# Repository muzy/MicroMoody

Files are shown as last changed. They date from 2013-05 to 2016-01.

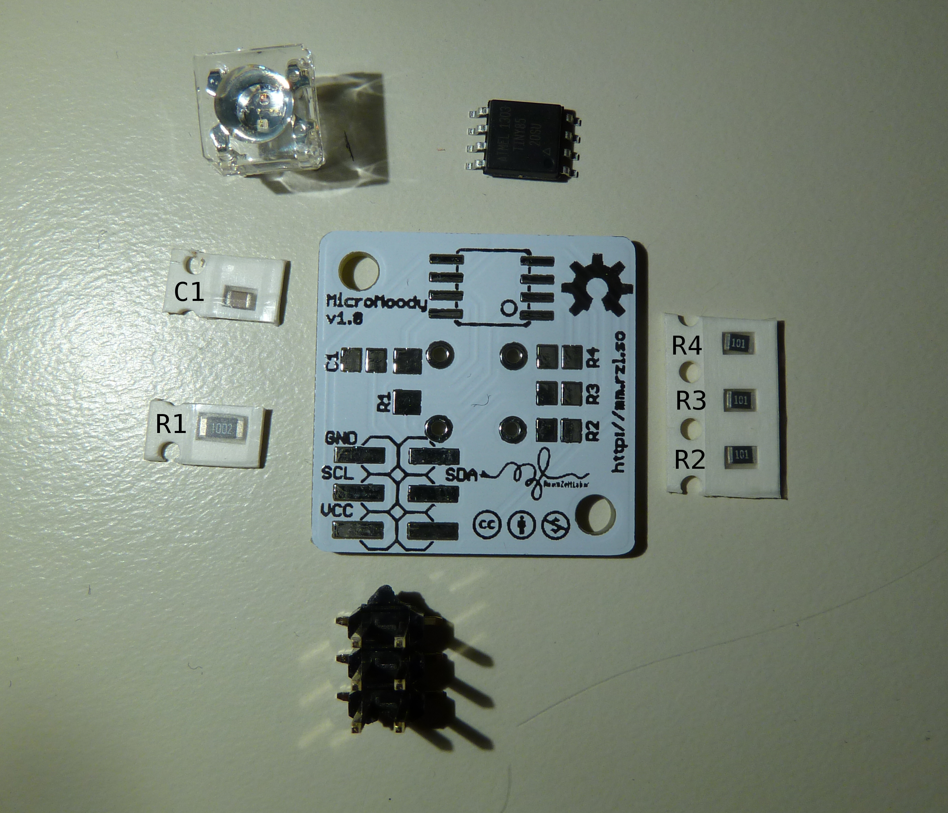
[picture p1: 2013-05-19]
doc/parts.jpg

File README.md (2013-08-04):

# MicroMoody

RGB LED driven by an ATTiny85. Largely blink(1)-compatible, except that it uses
I2C instead of USB.

## setup

See <https://wiki.chaosdorf.de/MicroMoody> and
<https://wiki.raumzeitlabor.de/wiki/MicroMoody> for soldering instructions.

For the firmware, run `make && make program`. You may need to edit the
Makefile to fit your programmer, it's written for an usbasp.

## remote control (I2C)

This is enabled by the `-DI2CEN` compile flag, which is set by default in the
Makefile. Hardware pull-ups on SCL and SDA are required (1.5 kOhm recommended)

After sending the 7bit address and the r/!w bit,
the bus master must send the following 7 bytes to the MicroMoody:

* command
* delay
* red value
* green value
* blue value
* payload address (high byte)
* payload address (low byte)

The default I2C address is `0x11` (17),
The default payload address is `0x0001`. The idea behind this distinction is
to use the I2C address to talk to any micromoody, and the payload address to
select the specific micromoody to address. This way, you can have various
other I2C devices and up to 65534 MicroMoodies on the same bus
(just in case you need to).

Commands with the broadcast payload address of `0xffff` are always accepted,
even when they contain the "set address" opmode.

red, green and blue are the color value, 0 is off, 0xff is full brightness.

There are several types of commands:

### command 0 .. 63 (set mode of operation)

The red, green and blue bytes are "don't care" unless a command is
marked `RGB`.

*   0: steady `RGB` light
*   1: rainbow colors, hard transitions
*   2: random colors, hard transitions
*   3: `RGB` color, blink on/off
*   4: steady light, fade to specified `RGB` color
*   5: rainbow colors, fading transitions
*   6: random colors, fading transitions
*   7: `RGB` color, fade on/off
*  63: Run animation. It will start in slot 1 and end in the slot last set
       (see also below)

modes 8 to 62 are reserved for further blink / fade modes.

### command 64 .. 127 (animation sequences)

*  64: Save `RGB` + delay in animation slot 1
* ...
* 127: Save `RGB` + delay in animation slot 64

For instance, to set a steady red pulse, you can transmit (in hex)
`40 10 ff 00 00 ff ff`, `41 10 50 00 00 ff ff`. This will make the animation
run in slot 1 -> slot 2 -> slot 1 -> ....

Note that this does not start the animation yet, use `3f XX XX XX XX ff ff`
for that. Also note that the upper bound of the current sequence is
determined by the last animation command. So if you send `40 ...`,
`41 ...`, `42 ...`, `40 ...`, the animation run will be
slot 1 -> slot 1 -> slot 1 -> .... (i.e. a steady color).

Refer to example/\*/rgbpulse for a more sophisticated example.

### command 128 .. 239

reserved

### command 240 .. 255 (EEPROM)

These commands access the EEPROM. Writing one byte takes about 3.4ms and is
implemented synchronously, so expect them to be slow. They may even cause I2C
bus timeouts (which do not indicate write failures).

* 240: Save current mode of operation (last command &lt; 64) to EEPROM to be
       recalled after a power cycle. NOTE: if the current opmode is 63
       (animation), this may take up to 1 second (~12ms for each used animation
       slot)
* 241: Set address to color bytes. payload high = red, payload low = green,
       i2c = blue. This will also set the operation mode to random fading.
       Note that for i2c, the least significant 7 bit are the address, while
       the most significant bit is ignored

commands 242 to 255 are reserved for further EEPROM commands.

## I2C master hardware

If you have an Arduino, see `examples/arduino/SerialToI2C` for a USB-Serial
to I2C interface.

Otherwise, see [vusb-i2c](https://github.com/derf/vusb-i2c) for a
general-purpose USB-I2C tool based on VUSB.

## recognizing the firmware state

At the time of this writing, a newly flashed MicroMoody with default address
will run the RGB blink mode (starting with yellow), while a newly flashed
MicroMoody with only the addresses changed and no mode set will run in
rgb fading mode (starting with green).

## I2C master operation

When compiled with -DI2CMASTER (disabled by default), the MicroMoody will act
as I2C bus master. After each transition (after half the time until the next
transition has passed) it will send its current color and fade delay as a
broadcast (payload address 0xffff) over the bus. The I2C address used will be
the MicroMoody's I2C address (see above for default).

If it is operating with hard transitions, so will the slaves. same for soft
(fading) transitions.

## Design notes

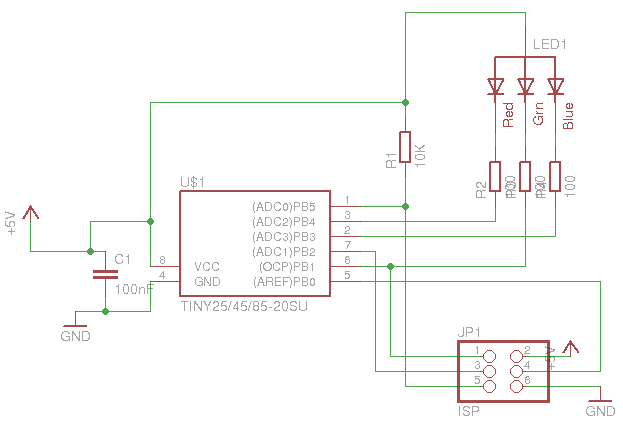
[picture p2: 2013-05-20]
schematics/circuit.png

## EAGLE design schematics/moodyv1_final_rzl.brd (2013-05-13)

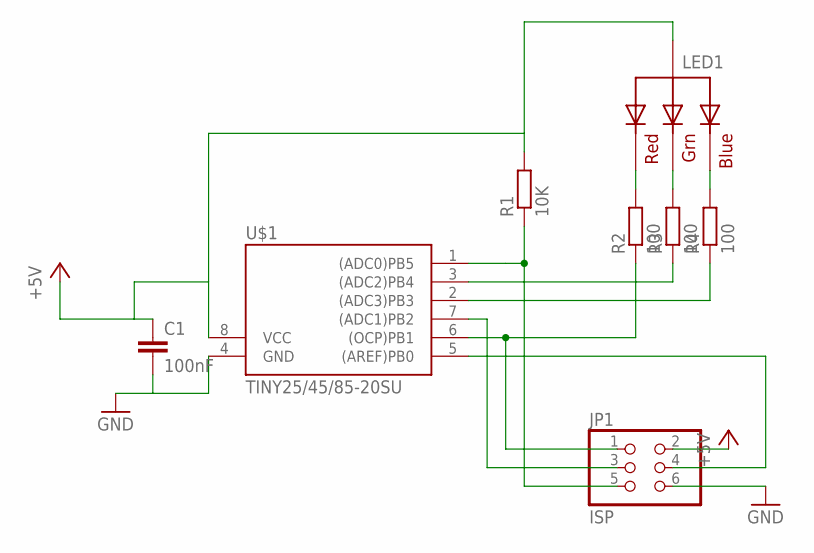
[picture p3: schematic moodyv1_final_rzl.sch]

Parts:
C1: 100nF; C0805
JP1: ISP; 2X03SMD
LED1: RGBLED_CA-PIRANHA; PIRANHA5MM
R1: 10K; R1206
R2, R3, R4: 100; R0805
U$1: TINY25/45/85-20SU; SOIC8

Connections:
+5V: C1.1, JP1.2, LED1.4 (VCC), R1.2, U$1.8 (VCC)
GND: C1.2, JP1.6, U$1.4 (GND)
unnamed: JP1.5, R1.1, U$1.1 ((ADC0)PB5)
unnamed: LED1.2 (RED), R2.2
unnamed: LED1.3 (GREEN), R3.2
unnamed: LED1.1 (BLUE), R4.2
unnamed: JP1.4, U$1.5 ((AREF)PB0)
unnamed: JP1.3, U$1.7 ((ADC1)PB2)
unnamed: JP1.1, R2.1, U$1.6 ((OCP)PB1)
unnamed: R4.1, U$1.2 ((ADC3)PB3)
unnamed: R3.1, U$1.3 ((ADC2)PB4)

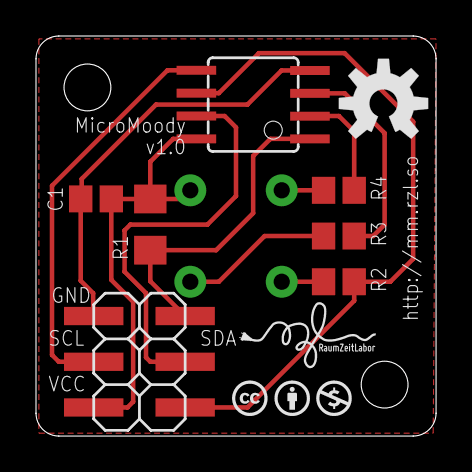
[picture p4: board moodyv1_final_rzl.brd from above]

Board: 2 copper layers, 22.2 x 22.2 mm, 8 parts (1 on the bottom side), 11 nets.

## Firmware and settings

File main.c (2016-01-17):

/*
 * Copyright (c) 2013, Daniel Friesel <derf@chaosdorf.de>
 *
 * Permission to use, copy, modify, and/or distribute this software for any
 * purpose with or without fee is hereby granted, provided that the above
 * copyright notice and this permission notice appear in all copies.
 */

#include <avr/eeprom.h>
#include <avr/io.h>
#include <stdlib.h>
#include <avr/pgmspace.h>
#include <avr/interrupt.h>

/*
 * PB1: green (OC1A)
 * PB3: blue  (soft pwm)
 * PB4: red   (OC1B)
 */

#define VRED   ( OCR1B   )
#define VGREEN ( OCR1A   )
#define VBLUE  ( is_blue )

#define OM_MODE_STEADY        (  0)
#define OM_MODE_BLINKRGB      (  1)
#define OM_MODE_BLINKRAND     (  2)
#define OM_MODE_BLINKONOFF    (  3)
#define OM_MODE_FADETOSTEADY  (  4)
#define OM_MODE_FADERGB       (  5)
#define OM_MODE_FADERAND      (  6)
#define OM_MODE_FADEONOFF     (  7)
#define OM_MODE_TEMPERATURE   (  8)
#define OM_MODE_STARTANIM     ( 63)
#define OM_MODE_ANIM_LOW      ( 64)
#define OM_MODE_ANIM_HIGH     (127)
#define OM_MODE_SAVESTATE     (240)
#define OM_MODE_SETADDR       (241)

#define TEMPERATURE_ZERO (355)

#define P_SDA PB0
#define P_SCL PB2

#ifdef I2CMASTER
#undef I2CEN
#endif

volatile uint8_t want_blue,  cache_blue;
volatile uint8_t want_green, cache_green;
volatile uint8_t want_red,   cache_red;

volatile uint8_t is_blue = 0;
volatile uint8_t opmode, speed;

volatile uint8_t seq[257];
volatile uint8_t step = 0;
volatile uint16_t animstep = 0;

volatile uint8_t addr_hi  = 0x00;
volatile uint8_t addr_lo  = 0x01;
volatile uint8_t addr_i2c = 0x11;

volatile enum {
	S_NONE, S_ACK, S_BYTE } comm_status = S_NONE;

uint8_t ee_valid, ee_mode, ee_speed, ee_red, ee_green, ee_blue EEMEM;
uint8_t ee_seq[257] EEMEM;
uint8_t ee_addrhi, ee_addrlo, ee_addri2c EEMEM;

const uint8_t pwmtable[32] PROGMEM = {
	0, 1, 2, 2, 2, 3, 3, 4, 5, 6, 7, 8, 10, 11, 13, 16, 19, 23,
	27, 32, 38, 45, 54, 64, 76, 91, 108, 128, 152, 181, 215, 255
};

int main (void)
{
	
	DDRB = _BV(DDB1) | _BV(DDB3) | _BV(DDB4);
	PORTB = _BV(PB1) | _BV(PB3) | _BV(PB4);

	uint8_t cnt = 0;

	WDTCR = _BV(WDE) | _BV(WDP3);

	TCCR0A = _BV(WGM01) | _BV(WGM00);
	TCCR0B = _BV(CS01);
	TIMSK = _BV(TOIE0);

	GTCCR = _BV(PWM1B) | _BV(COM1B1) | _BV(COM1B0);
	TCCR1 = _BV(PWM1A) | _BV(COM1A1) | _BV(COM1A0) | _BV(CS10);
	OCR1A = 0;
	OCR1B = 0;
	OCR1C = 0xff;

	if (eeprom_read_byte(&ee_valid) == 1) {
		VRED   = want_red   = cache_red   = eeprom_read_byte(&ee_red);
		VGREEN = want_green = cache_green = eeprom_read_byte(&ee_green);
		VBLUE  = want_blue  = cache_blue  = eeprom_read_byte(&ee_blue);

		opmode   = eeprom_read_byte(&ee_mode);
		speed    = eeprom_read_byte(&ee_speed);
		addr_hi  = eeprom_read_byte(&ee_addrhi);
		addr_lo  = eeprom_read_byte(&ee_addrlo);
		addr_i2c = eeprom_read_byte(&ee_addri2c);

		if (opmode == OM_MODE_STARTANIM) {
			VRED = VGREEN = VBLUE = speed = 0;
			seq[256] = eeprom_read_byte(&ee_seq[256]);
			for (cnt = 0; cnt < 255; cnt++)
				seq[cnt] = eeprom_read_byte(&ee_seq[cnt]);
			seq[255] = eeprom_read_byte(&ee_seq[255]);
		}
	} else {
		opmode = OM_MODE_BLINKRGB;
		speed  = 32;
		VRED   = want_red   = cache_red   = 255;
		VGREEN = want_green = cache_green = 255;
		VBLUE  = want_blue  = cache_blue  = 0;
	}


#ifdef I2CEN
	USICR = _BV(USIWM1) | _BV(USICS1);
	USISR = 0xf0;
	DDRB &= ~_BV(P_SDA);
	PORTB &= ~_BV(P_SDA);
	DDRB |= _BV(P_SCL);
	PORTB |= _BV(P_SCL);
	USICR |= _BV(USISIE);

#endif

#ifdef TEMPERATURE

	ADMUX = _BV(REFS1) | 0x0f;
	ADCSRB = _BV(ADTS2);
	ADCSRA = _BV(ADEN) | _BV(ADATE);
	ADCSRA |= _BV(ADSC);

#endif /* TEMPERATURE */

	sei();

	while (1) {
		cnt++;
		if (cnt == 0 && VBLUE) {
			PORTB &= ~_BV(PB3);
		}
		if (cnt == VBLUE)
			PORTB |= _BV(PB3);
	}

	return 0;
}

#ifdef I2CMASTER

#define TWI_DELAY_SHORT 8
#define TWI_DELAY_LONG  42

/*
 * since we're doing software pwm, we can't wait for slaves. so this will
 * probably only work on a bus exclusively used by MicroMoodies.
 * TODO: move soft pwm to interrupt handler?
 * Also TODO: Use hardware shift register (USIDR). Fixes welcome.
 */

void sda_high() {
	DDRB  &= ~_BV(PB0);
}

void sda_low() {
	DDRB  |=  _BV(PB0);
}

void scl_high() {
	DDRB  &= ~_BV(PB2);
}

void scl_low() {
	DDRB  |=  _BV(PB2);
}

void twi_delay(uint8_t delay)
{
	uint8_t i;
	for (i = 0; i < delay; i++)
		asm("nop");
}

void twi_tx_byte(uint8_t byte)
{
	int8_t i;

	for (i = 7; i >= -1; i--) {
		twi_delay(TWI_DELAY_SHORT);
		if ((i < 0) || (byte & _BV(i)))
			sda_high();
		else
			sda_low();
		twi_delay(TWI_DELAY_SHORT);
		scl_high();
		twi_delay(TWI_DELAY_SHORT);
		scl_low();
	}
	twi_delay(TWI_DELAY_LONG);
}


#endif /* I2CMASTER */

ISR(TIMER0_OVF_vect)
{
	uint8_t seq_addr;

#ifdef I2CMASTER
	static uint8_t i2cstep = 0;
#endif

#ifdef TEMPERATURE
	int16_t thermal = 0;

	if (opmode == OM_MODE_TEMPERATURE) {
		thermal = ADCL;
		thermal |= (ADCH << 8);
		thermal -= TEMPERATURE_ZERO;
	}
#endif

	step++;
	if ((step % 64) == 0)
		animstep++;

	if (( ((step % ( ( speed ) * 1)) == 0) )
			&& (opmode >= 4) ) {

		if (VRED > want_red)
			VRED--;
		if (VRED < want_red)
			VRED++;
		if (VGREEN > want_green)
			VGREEN--;
		if (VGREEN < want_green)
			VGREEN++;
		if (VBLUE > want_blue)
			VBLUE--;
		if (VBLUE < want_blue)
			VBLUE++;
	}

#ifdef I2CMASTER
	if ((animstep == ( ( (uint16_t)speed) << 0) ) && (i2cstep <= 3)) {
		switch (i2cstep) {
			case 0:
				sda_low();
				break;
			case 1:
				scl_low();
				break;
			case 2:
				twi_tx_byte(addr_i2c << 1);
				if (opmode >= 4) {
					twi_tx_byte(OM_MODE_FADETOSTEADY);
					twi_tx_byte(speed);
					twi_tx_byte(want_red);
					twi_tx_byte(want_green);
					twi_tx_byte(want_blue);
				}
				else {
					twi_tx_byte(OM_MODE_STEADY);
					twi_tx_byte(speed);
					twi_tx_byte(VRED);
					twi_tx_byte(VGREEN);
					twi_tx_byte(VBLUE);
				}
				break;
			case 3:
				twi_tx_byte(0xff);
				twi_tx_byte(0xff);
				scl_high();
				sda_high();
				break;
		}

		i2cstep++;
	}
#endif

	if (animstep == ( ( (uint16_t)speed ) << 2 ) ) {
		animstep = 0;
#ifdef I2CMASTER
		i2cstep = 0;
#endif
		switch (opmode) {
			case OM_MODE_BLINKRGB:
				if (!VBLUE && VRED && !VGREEN)
					VGREEN = 255;
				else if (VRED && VGREEN)
					VRED = 0;
				else if (VGREEN && !VBLUE)
					VBLUE = 255;
				else if (VGREEN && VBLUE)
					VGREEN = 0;
				else if (VBLUE && !VRED)
					VRED = 255;
				else if (VBLUE && VRED)
					VBLUE = 0;
				else
					VRED = 255;
				break;
			case OM_MODE_BLINKRAND:
				VRED   = pwmtable[ rand() & 32 ];
				VGREEN = pwmtable[ rand() & 32 ];
				VBLUE  = pwmtable[ rand() & 32 ];
				break;
			case OM_MODE_BLINKONOFF:
				if ((VRED == cache_red) && (VGREEN == cache_green)
						&& (VBLUE == cache_blue)) {
					VRED = VGREEN = VBLUE = 0;
				}
				else {
					VRED   = cache_red;
					VGREEN = cache_green;
					VBLUE  = cache_blue;
				}
				break;
			case OM_MODE_FADEONOFF:
				if ((want_red == cache_red) && (want_green == cache_green)
						&& (want_blue == cache_blue)) {
					want_red = want_green = want_blue = 0;
				}
				else {
					want_red   = cache_red;
					want_green = cache_green;
					want_blue  = cache_blue;
				}
				break;
			case OM_MODE_FADERGB:
				if (!want_blue && want_red && !want_green)
					want_green = 255;
				else if (want_red && want_green)
					want_red = 0;
				else if (want_green && !want_blue)
					want_blue = 255;
				else if (want_green && want_blue)
					want_green = 0;
				else if (want_blue && !want_red)
					want_red = 255;
				else if (want_blue && want_red)
					want_blue = 0;
				else
					want_red = 255;
				break;
			case OM_MODE_FADERAND:
				want_red   = pwmtable[ rand() & 32 ];
				want_green = pwmtable[ rand() & 32 ];
				want_blue  = pwmtable[ rand() & 32 ];
				break;
			case OM_MODE_FADETOSTEADY:
				break;
#ifdef TEMPERATURE
			case OM_MODE_TEMPERATURE:
				VGREEN = 0;

				if (thermal < 0)
					VBLUE = 0xff;
				else if (thermal < 32)
					VBLUE = pwmtable[31 - thermal];
				else
					VBLUE = 0;

				if (thermal < 20)
					VRED = 0;
				else if (thermal < 52)
					VRED = pwmtable[thermal - 20];
				else
					VRED = 0xff;
				break;
#endif /* TEMPERATURE */
			case OM_MODE_STARTANIM:
				opmode = OM_MODE_ANIM_LOW;
				// fall-through
			default:
				if ((opmode >= OM_MODE_ANIM_LOW) && (opmode < OM_MODE_ANIM_HIGH)) {
					seq_addr = (opmode - OM_MODE_ANIM_LOW) * 4;
					speed      = seq[ seq_addr + 0 ];
					want_red   = seq[ seq_addr + 1 ];
					want_green = seq[ seq_addr + 2 ];
					want_blue  = seq[ seq_addr + 3 ];

					if (opmode >= seq[256])
						opmode = OM_MODE_ANIM_LOW;
					else
						opmode++;
				}
				break;
		}
	}

	asm("wdr");
}

#ifdef I2CEN

ISR(USI_START_vect)
{
	// Wait for SCL to go low to ensure the "Start Condition" has completed.
	// otherwise the counter will count the transition
	while ( PINB & _BV(P_SCL) ) ;
	USISR = 0xf0; // write 1 to clear flags; clear counter
	// enable USI interrupt on overflow; SCL goes low on overflow
	USICR |= _BV(USIOIE) | _BV(USIWM0);
	comm_status = S_NONE;
}

ISR(USI_OVF_vect)
{
	static uint8_t rcvbuf[7];
	static uint8_t rcvcnt = sizeof(rcvbuf);
	uint8_t seq_addr;

	switch (comm_status) {
		case S_NONE:
			if ((USIDR & 0xfe) == (addr_i2c << 1)) {
				rcvcnt = sizeof(rcvbuf);
				DDRB |= _BV(P_SDA);
				USISR = 0x0e;
				comm_status = S_ACK;
			}
			else {
				USICR &= ~(_BV(USIOIE) | _BV(USIWM0));
			}
			break;
		case S_ACK:
			DDRB &= ~_BV(P_SDA);
			comm_status = S_BYTE;
			break;
		case S_BYTE:
			rcvbuf[--rcvcnt] = USIDR;
			DDRB |= _BV(P_SDA);
			USISR = 0x0e;
			comm_status = S_ACK;
			break;
	}

	if (!rcvcnt && (comm_status == S_BYTE)) {
		comm_status = S_NONE;
		USICR &= ~(_BV(USIOIE) | _BV(USIWM0));
		rcvcnt = sizeof(rcvbuf);
		if (
				(((rcvbuf[1] == addr_hi) && (rcvbuf[0] == addr_lo))
				 || ((rcvbuf[1] == 0xff) && (rcvbuf[0] == 0xff)))) {
			step = animstep = 0;

			if (rcvbuf[6] < 4) {
				VRED   = cache_red   = rcvbuf[4];
				VGREEN = cache_green = rcvbuf[3];
				VBLUE  = cache_blue  = rcvbuf[2];
			}
			else if (rcvbuf[6] < 8) {
				want_red   = cache_red   = rcvbuf[4];
				want_green = cache_green = rcvbuf[3];
				want_blue  = cache_blue  = rcvbuf[2];
			}
			else if (rcvbuf[6] == OM_MODE_SETADDR) {
				addr_hi  = rcvbuf[4];
				addr_lo  = rcvbuf[3];
				addr_i2c = rcvbuf[2];

				opmode = OM_MODE_FADERGB;
				speed = 64;
				want_red = cache_red = 0;
				want_green = cache_green = 255;
				want_blue = cache_blue = 0;
			}

			if (rcvbuf[6] <= OM_MODE_STARTANIM) {
				opmode = rcvbuf[6];
				speed = rcvbuf[5];
			}
			else if (rcvbuf[6] < OM_MODE_ANIM_HIGH) {
				seq_addr = (rcvbuf[6] - OM_MODE_ANIM_LOW) * 4;
				seq[ seq_addr + 0 ] = rcvbuf[5];
				seq[ seq_addr + 1 ] = rcvbuf[4];
				seq[ seq_addr + 2 ] = rcvbuf[3];
				seq[ seq_addr + 3 ] = rcvbuf[2];
				seq[256] = rcvbuf[6];
			}
			else if (rcvbuf[6] >= OM_MODE_SAVESTATE) {
				if (opmode > OM_MODE_STARTANIM)
					opmode = OM_MODE_STARTANIM;
				eeprom_write_byte(&ee_valid, 1);
				eeprom_write_byte(&ee_addrhi, addr_hi);
				eeprom_write_byte(&ee_addrlo, addr_lo);
				eeprom_write_byte(&ee_addri2c, addr_i2c);
				eeprom_write_byte(&ee_mode, opmode);
				if (opmode < OM_MODE_STARTANIM) {
					eeprom_write_byte(&ee_speed, speed);
					eeprom_write_byte(&ee_red, cache_red);
					eeprom_write_byte(&ee_green, cache_green);
					eeprom_write_byte(&ee_blue, cache_blue);
				}
				else {
					eeprom_write_byte(&ee_seq[256], seq[256]);
					if (seq[256] == OM_MODE_ANIM_HIGH) {
						for (seq_addr = 0; seq_addr < 255; seq_addr++)
						eeprom_write_byte(&ee_seq[seq_addr], seq[seq_addr]);
						eeprom_write_byte(&ee_seq[255], seq[255]);
					}
					else {
						for (seq_addr = 0; seq_addr <= ((seq[256] - OM_MODE_ANIM_LOW) * 4 + 3); seq_addr++) {
							eeprom_write_byte(&ee_seq[seq_addr], seq[seq_addr]);
						}
					}
				}
			}
		}
	}

	USISR |= _BV(USIOIF);
}

#endif /* I2CEN */

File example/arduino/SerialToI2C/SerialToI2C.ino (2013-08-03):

/*
 * I2C Master on an Arduino Nano. A5 is SCL, A4 is SDA.
 * 1k5 hardware pull-ups from SDA and SCL to VCC are required.
 * Also, make sure there is no connection between Pin 1
 * of any twoo MicroMoodies.
 *
 * Passes any serial data on to the micromoody bus.
 * Example input: "17,0,0,255,255,0,255,255" will set
 * all moodies to yellow.
 */

#include <Wire.h>

void setup()
{
  Serial.begin(9600);
  Wire.begin();
}

void loop()
{
  byte data[8], i, ret;
  while (Serial.available()) {
    for (i = 0; i < 8; i++) {
      data[i] = (byte)Serial.parseInt();
    }
      
    Serial.print("sending:");
    Wire.beginTransmission(data[0]);
    for (i = 1; i < 8; i++) {
      Serial.print(" ");
      Serial.print(data[i], HEX);
      Wire.write(data[i]);
    }
    ret = Wire.endTransmission();
    switch (ret) {
      case 0: Serial.println(" -> OK"); break;
      case 1: Serial.println(" -> ERR: Data too long"); break;
      case 2: Serial.println(" -> ERR: address NAKd"); break;
      case 3: Serial.println(" -> OK/ERR: data NAKd"); break;
      case 4: Serial.println(" -> ERR: unknown error"); break;
    }
  }
}

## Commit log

2013-03-15 Add schematic
    [moodyv1_rzl.brd, moodyv1_rzl.sch]
2013-03-15 move schematics to folder schematics
    [moodyv1_rzl.brd, moodyv1_rzl.sch]
2013-03-15 fading demo code using soft pwm
2013-04-19 use hardware pwm for green and red
2013-04-25 implement various blinkenlight modes (based on blinkencontrol). TODO: I2C
2013-05-10 working I2C communication \o/
2013-05-12 makefile: add .lss target (assembly listing)
2013-05-12 tried to fix addrlo receive. still unreliable. what!
    [main.c]
2013-05-13 fix fading (allow time for full 0xff <-> 0x00 transition)
    [main.c]
2013-05-13 Now: Real I2C. with start condition detection and no bugs so far
    [main.c]
2013-05-13 add I2C command to set address
2013-05-13 README: Add link to USB -> I2C bridge
2013-05-13 add newest schematic
    [moodyv1_final_rzl.brd, moodyv1_final_rzl.sch, moodyv1_rzl.brd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]
2013-05-13 remove uneccesary files
    [moodyv1_rzl.brd, moodyv1_rzl.sch]
2013-05-17 enable temperature mode. it's still broken.
    [main.c]
2013-05-20 add circuit.png
2013-05-20 Fix ADC initialization (temperature sensor readout should work now)
    [main.c]
2013-05-26 add (not very good) I2C bus master support
2013-05-28 run I2C master code without flickering
2013-05-29 i2cmaster: wait less than 50% until command propagation
2013-05-31 fix variable mis-declaration without I2CMASTER
    [main.c]
2013-06-07 leave space for I2C ack bit (we don't send an ack yet, though!)
2013-07-12 proper i2c support with ack (and nak after last byte)
2013-07-25 fix off-by-one in addr_i2c (write == 0, we don't support read...)
    [main.c]
2013-07-26 fix i2c address usage
    [main.c]
2013-07-28 fix i2c master mode
    [main.c]
2013-07-31 Add example for an arduino as i2c master and three modies
2013-07-31 Arduino/Wire example: shorten code
    [Wire.ino]
2013-07-31 add vusb-i2c example
2013-08-03 add RGBPulse arduino example (identical to vusb-i2c/rgbpulse)
2013-08-03 Add arduino serial -> I2C example
2016-01-17 USI receive: Fix a (surprisingly harmess) typo after receipt of the last byte
    [main.c]
2016-01-17 I2C receive: Acknowledge the last byte
